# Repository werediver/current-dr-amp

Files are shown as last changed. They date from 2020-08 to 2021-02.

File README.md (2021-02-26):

# CURRENT DR.

This is a "current drive" or VCCS class A headphone amplifier. Some advocacy of current drive (as well as a whole book on the topic) can be found at [current-drive.info](https://www.current-drive.info/6).

The first prototype is briefly described on [Prototype](texts/prototype.md) page.

## Schematic

The current version of the schematic is showed below.

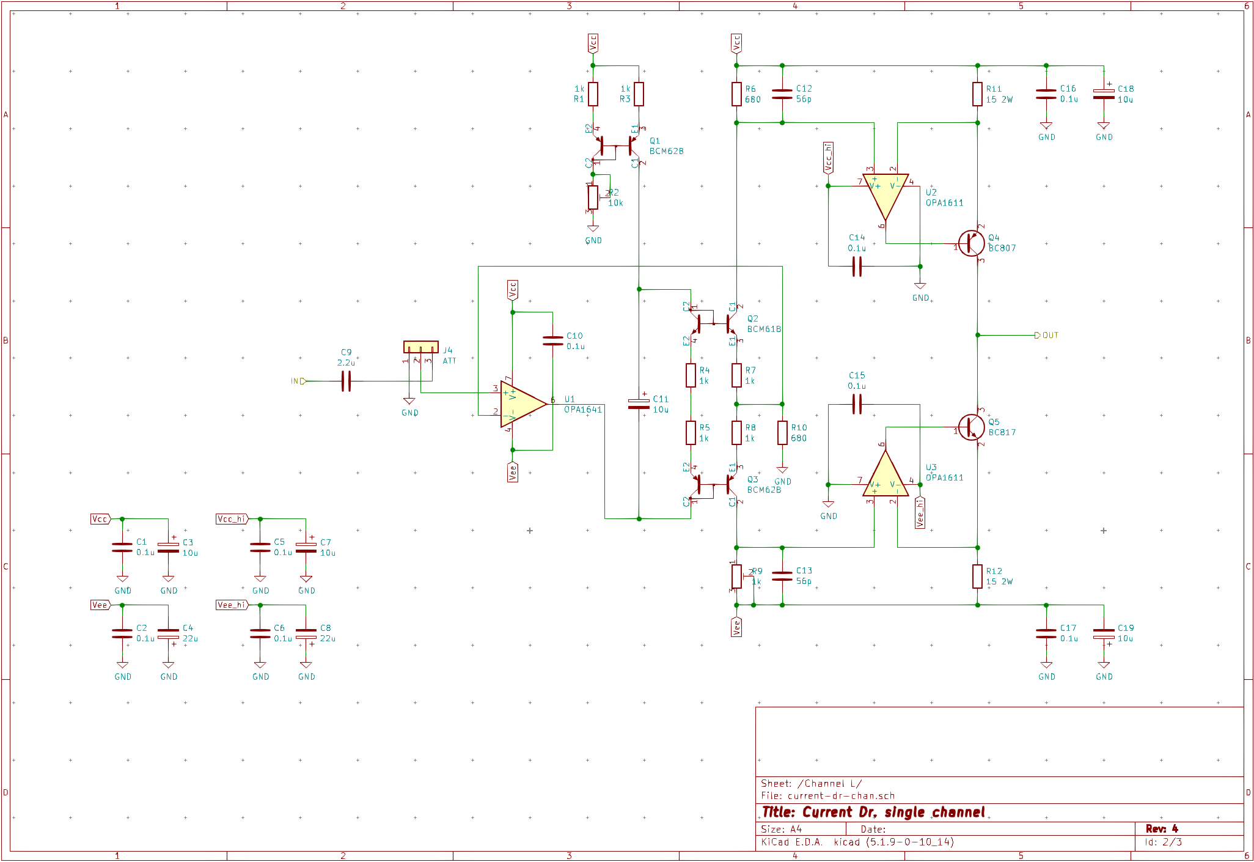
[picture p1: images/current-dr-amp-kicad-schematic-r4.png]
Current Dr. schematic


Two such channels with a dedicated [linear PSU](texts/psu.md) are going to be fit into an extruded aluminum enclosure with internal dimensions of 96x155x50 mm.

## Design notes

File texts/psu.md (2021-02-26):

# Power supply unit

A double bipolar linear PSU with discrete low-dropout voltage regulators is designed for Current Dr. amplifier.

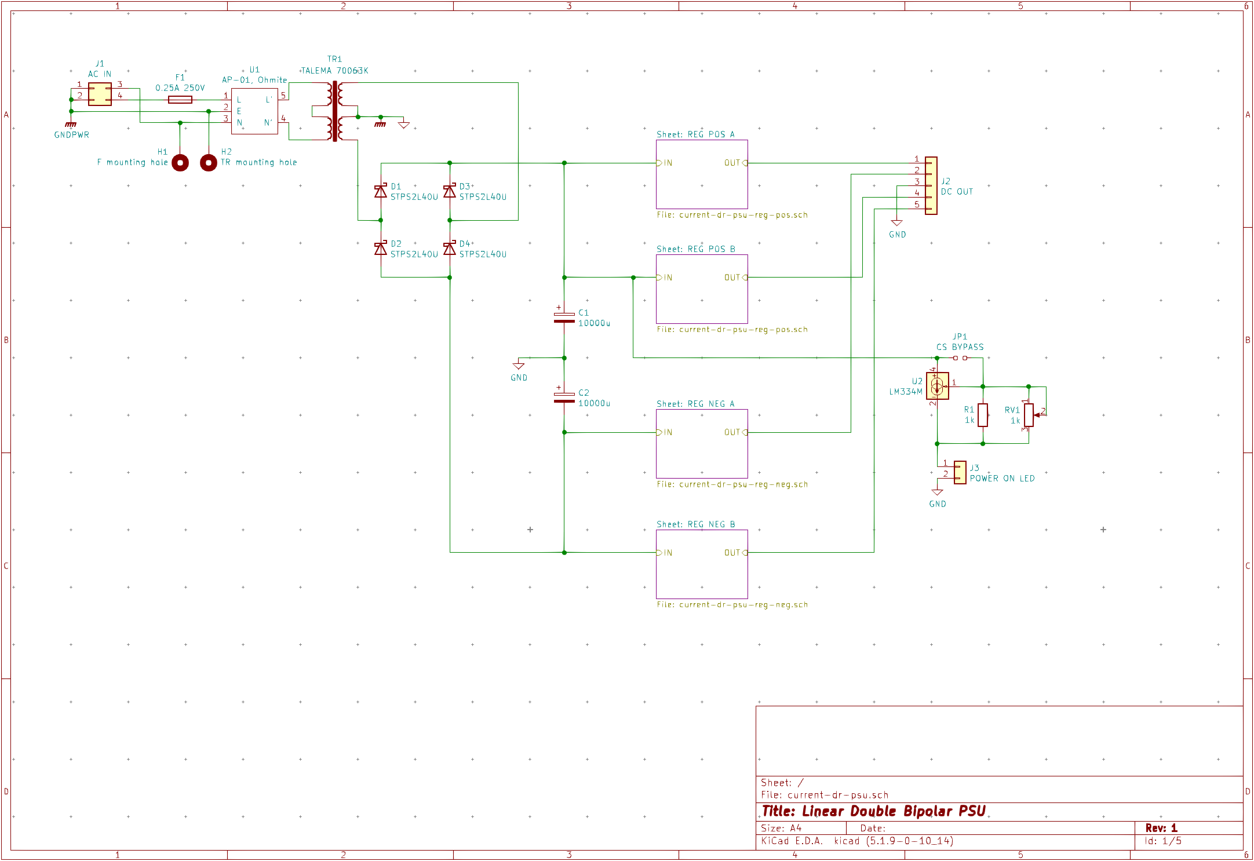
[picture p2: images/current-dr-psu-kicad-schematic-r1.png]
Top-level PSU schematic


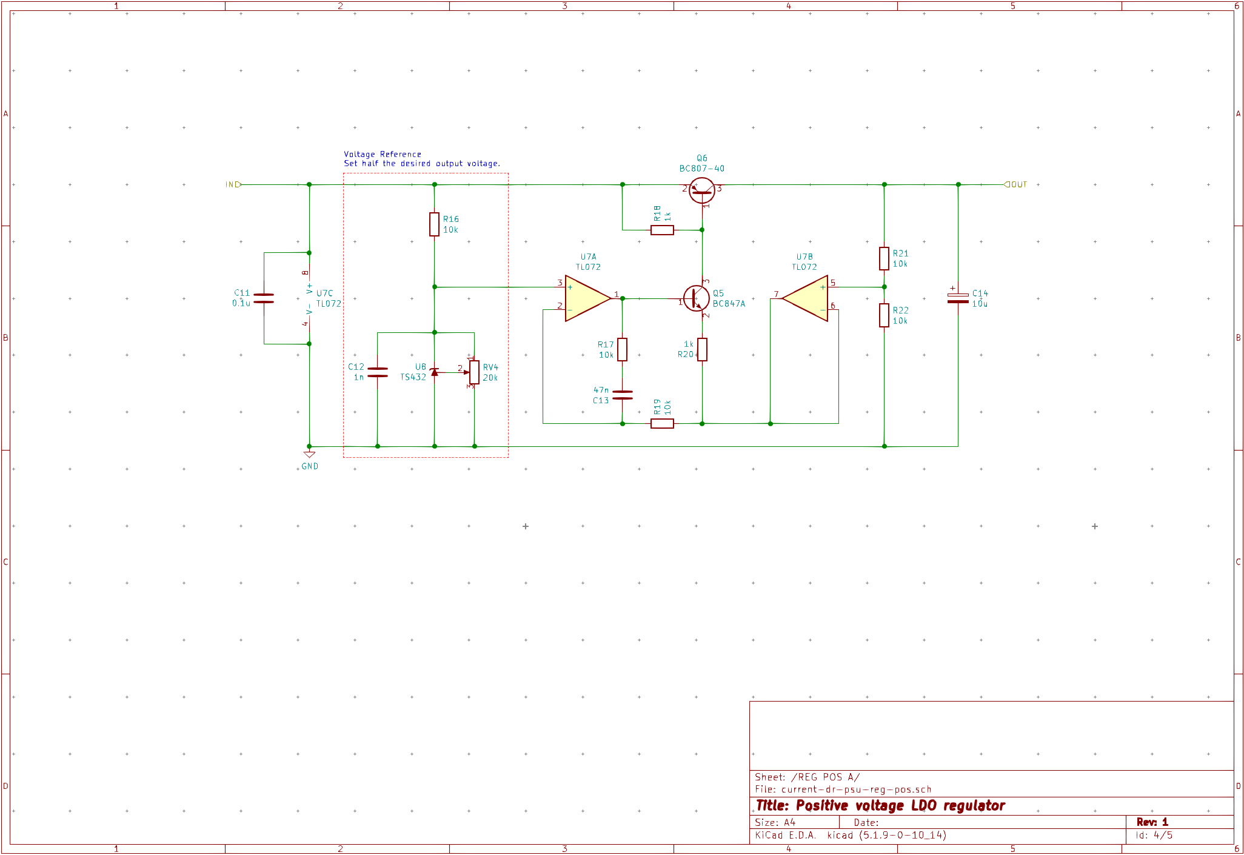
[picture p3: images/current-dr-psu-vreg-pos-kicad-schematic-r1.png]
Discrete positive low-dropout voltage regulator


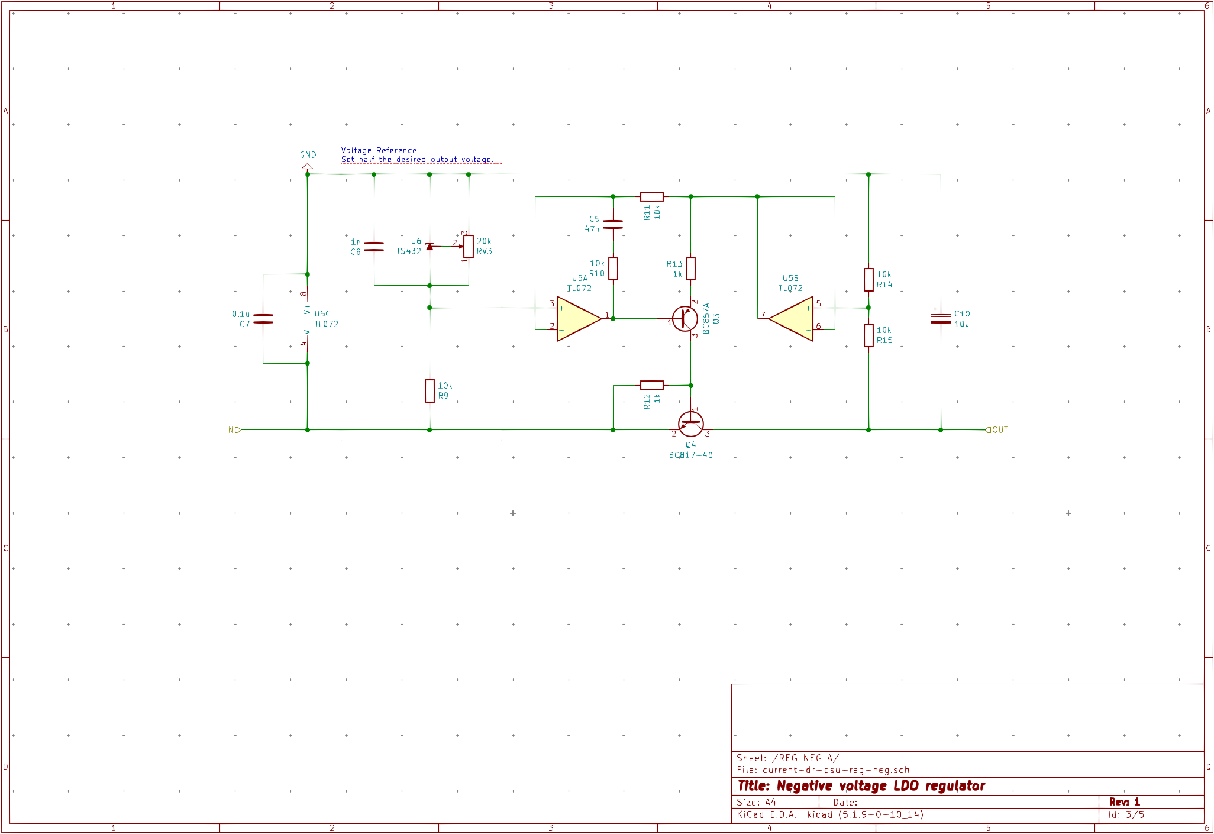
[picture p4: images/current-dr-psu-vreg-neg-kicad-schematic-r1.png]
Discrete negative low-dropout voltage regulator


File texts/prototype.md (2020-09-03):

# Prototype

A single channel of the Current Dr. amplifier has been prototyped according to the following schematic.

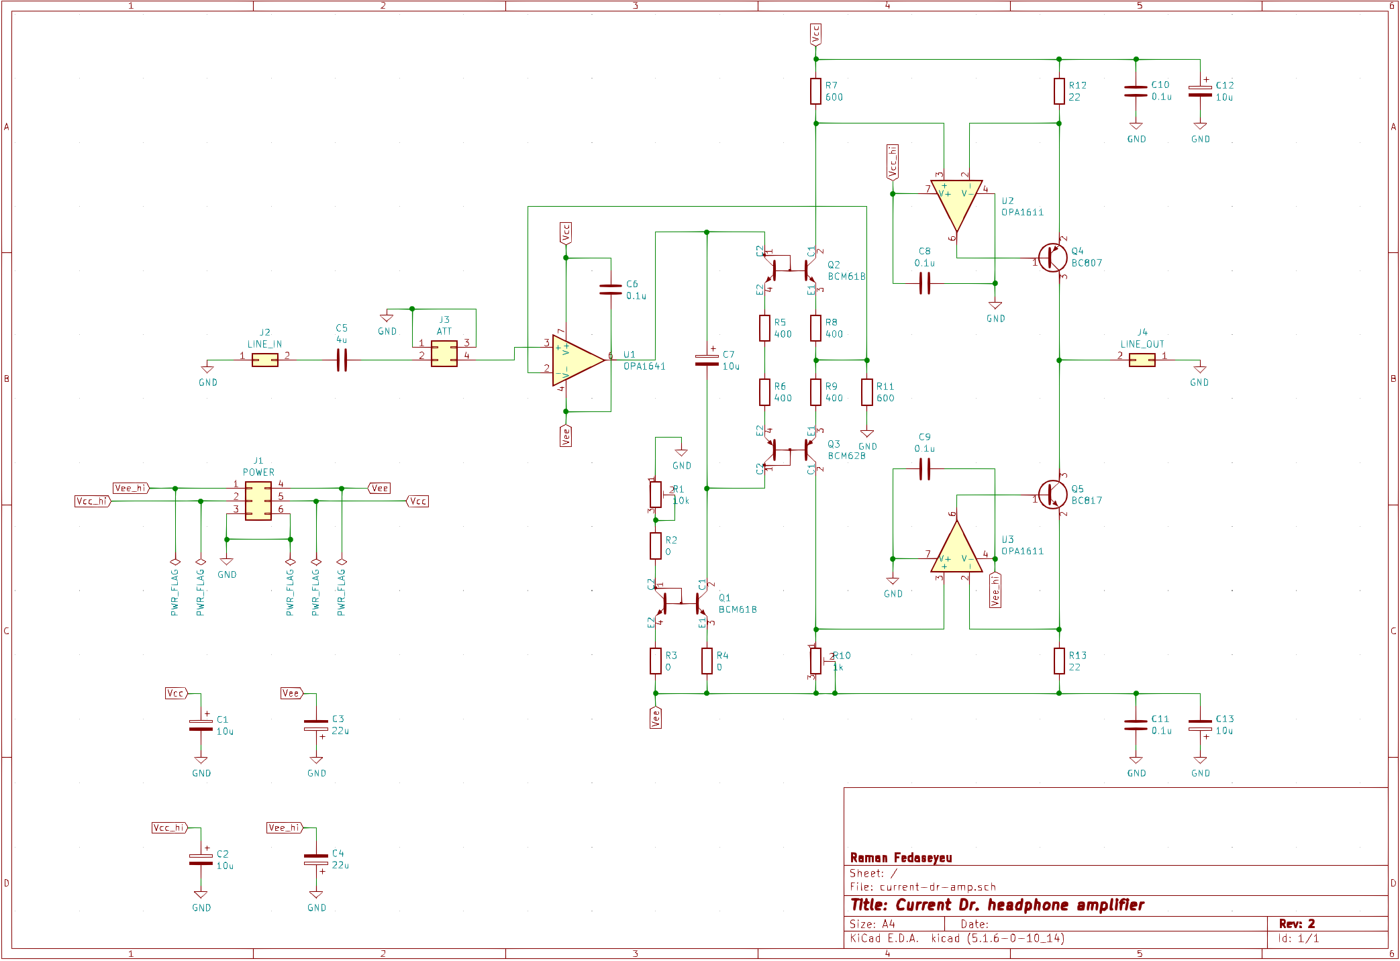
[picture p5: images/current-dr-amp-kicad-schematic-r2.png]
KiCad schematic


There are a few placeholder components present (R2–R4) and some were added after debugging the prototype (C1–C4).

The initial set-up consists of two operations:

- setting the quiescent current through the reference current sink Q2–Q3 to about 2.5 mA by adjusting R1 and measuring the voltage drop across R5–R6
- setting the output DC offset to a fraction of a mV by adjusting R10 and measuring voltage at the output with a load connected (a resistor of a few hundreds ohm is a suitable load)

The assembled prototype looks like this.

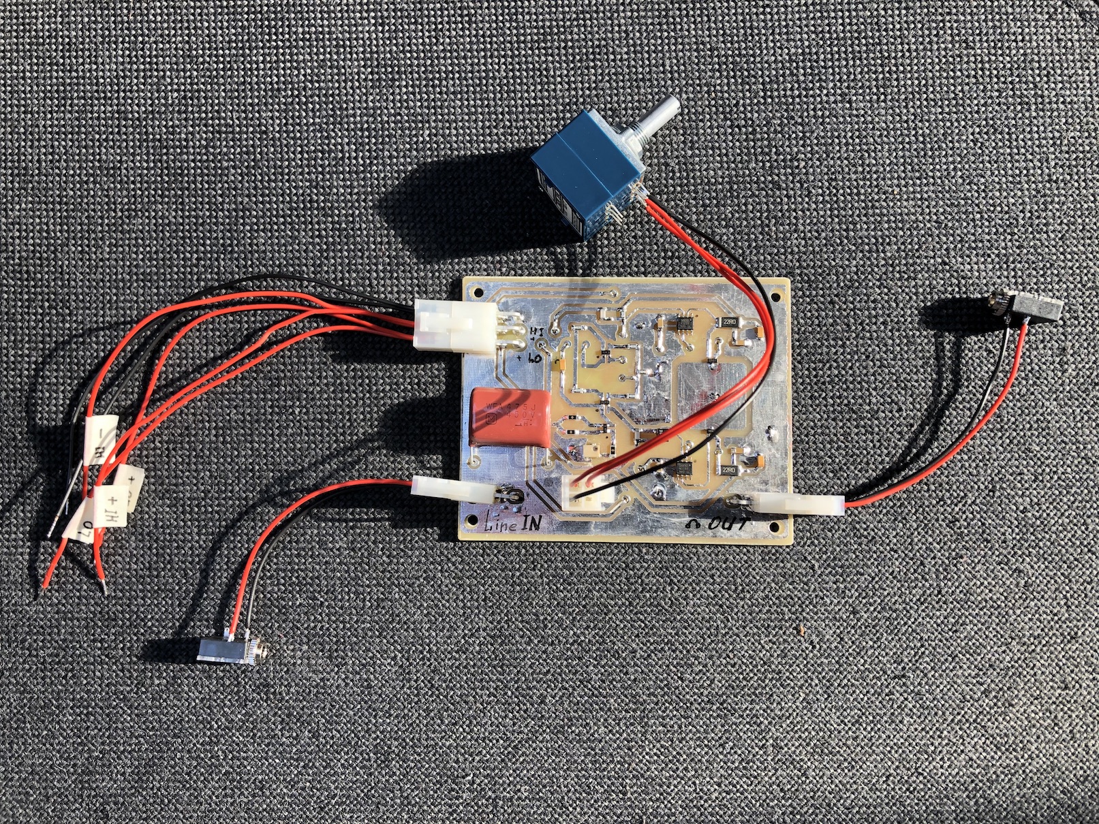
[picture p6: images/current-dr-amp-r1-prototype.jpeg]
Prototype


I haven't been able to measure the frequency response, THD, or the output impedance of the prototype yet. Listening to a single channel output suggests it has some potential, hence a proper characterization and development of a standalone stereo amplifier is to be done.

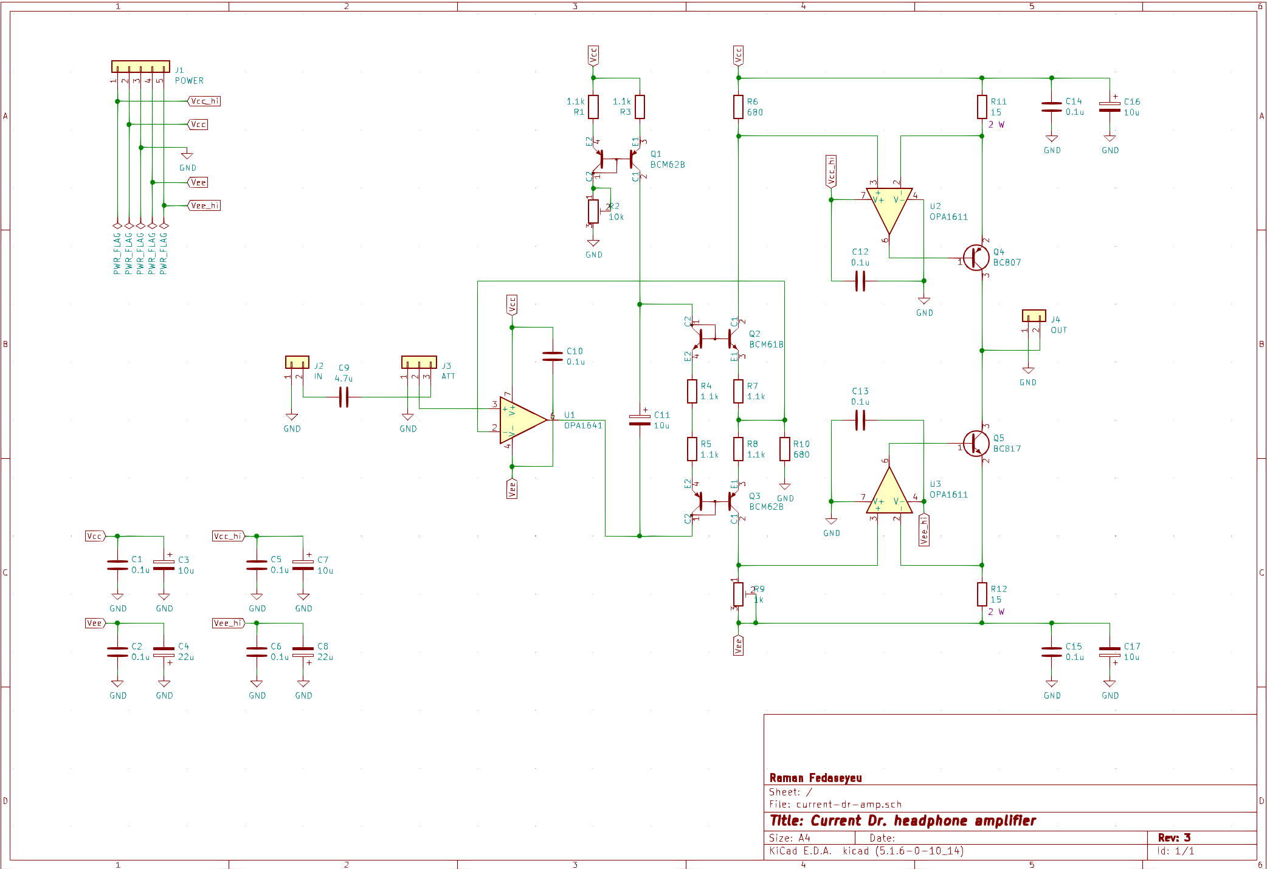
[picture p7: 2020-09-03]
images/current-dr-amp-kicad-schematic-r3.png

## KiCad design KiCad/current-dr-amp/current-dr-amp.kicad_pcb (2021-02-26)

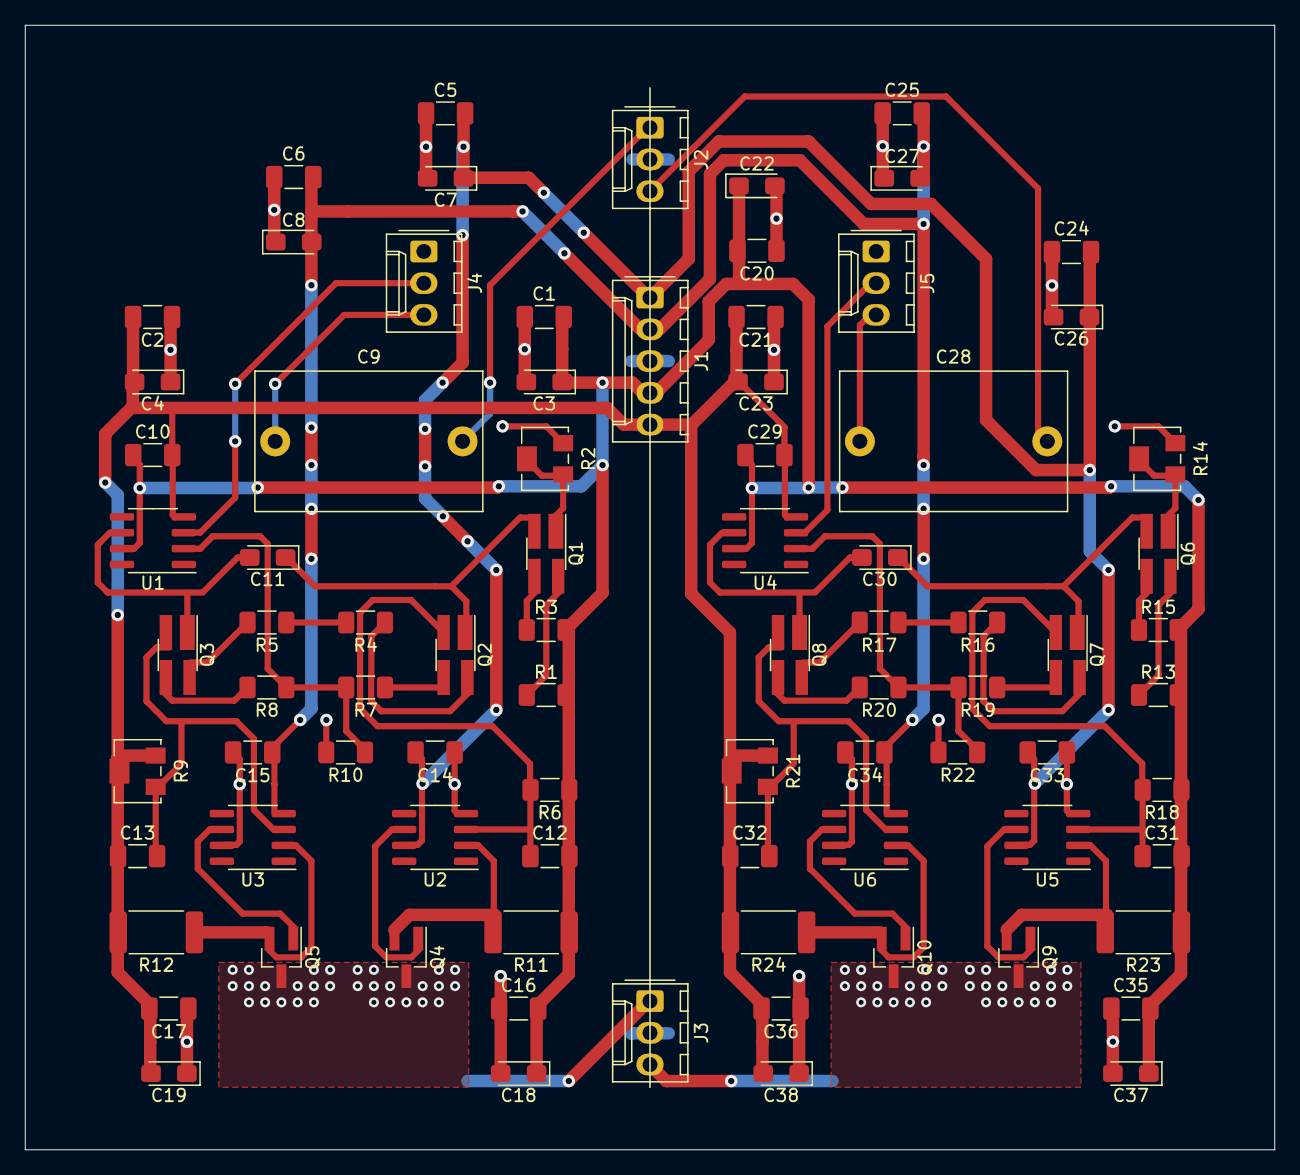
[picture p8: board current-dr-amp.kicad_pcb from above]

Board: 2 copper layers, 100.0 x 90.0 mm, 83 parts (0 on the bottom side), 47 nets.

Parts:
C1, C2, C5, C6, C10, C14, C15, C16, C17, C20, C21, C24, C25, C29, C33, C34, C35, C36: 0.1u; C_1206_3216Metric_Pad1.33x1.80mm_HandSolder
C3, C7, C11, C18, C19, C22, C26, C30, C37, C38: 10u; CP_EIA-3216-10_Kemet-I_Pad1.58x1.35mm_HandSolder
C4, C8, C23, C27: 22u; CP_EIA-3216-10_Kemet-I_Pad1.58x1.35mm_HandSolder
C9, C28: 2.2u; C_Rect_L18.0mm_W11.0mm_P15.00mm_FKS3_FKP3
C12, C13, C31, C32: 56p; C_1206_3216Metric_Pad1.33x1.80mm_HandSolder
J1: POWER; Molex_KK-254_AE-6410-05A_1x05_P2.54mm_Vertical
J2: IN; Molex_KK-254_AE-6410-03A_1x03_P2.54mm_Vertical
J3: OUT; Molex_KK-254_AE-6410-03A_1x03_P2.54mm_Vertical
J4, J5: ATT; Molex_KK-254_AE-6410-03A_1x03_P2.54mm_Vertical
Q1, Q3, Q6, Q8: BCM62B; SOT-143_Handsoldering
Q2, Q7: BCM61B; SOT-143_Handsoldering
Q4, Q9: BC807; SOT-23_Handsoldering
Q5, Q10: BC817; SOT-23_Handsoldering
R1, R3, R4, R5, R7, R8, R13, R15, R16, R17, R19, R20: 1k; R_1206_3216Metric_Pad1.30x1.75mm_HandSolder
R2, R14: 10k; Potentiometer_Bourns_3224W_Vertical
R6, R10, R18, R22: 680; R_1206_3216Metric_Pad1.30x1.75mm_HandSolder
R9, R21: 1k; Potentiometer_Bourns_3224W_Vertical
R11, R12, R23, R24: 15 2W; R_2512_6332Metric_Pad1.40x3.35mm_HandSolder
U1, U4: OPA1641; SOIC-8_3.9x4.9mm_P1.27mm
U2, U3, U5, U6: OPA1611; SOIC-8_3.9x4.9mm_P1.27mm

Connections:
/Channel L/IN: C9.2, J2.1
/Channel L/OUT: J3.1, Q4.3, Q5.3
/Channel R/IN: C28.2, J2.3
/Channel R/OUT: J3.3, Q9.3, Q10.3
GND: C1.1, C2.1, C3.2, C4.1, C5.1, C6.1, C7.2, C8.1, C14.1, C15.2, C16.1, C17.1, C18.2, C19.1, C20.1, C21.1, C22.2, C23.1, C24.1, C25.1, C26.2, C27.1, C33.1, C34.2, C35.1, C36.1, C37.2, C38.1, J1.3, J2.2, J3.2, J4.1, J5.1, R2.3, R10.2, R14.3, R22.2, U2.4, U3.7, U5.4, U6.7
unnamed: C9.1, J4.3
unnamed: C11.1, Q1.2, Q2.1
unnamed: C11.2, Q3.1, U1.6
unnamed: C12.1, Q2.2, R6.2, U2.3
unnamed: C13.2, Q3.2, R9.1, U3.3
unnamed: C28.1, J5.3
unnamed: C30.1, Q6.2, Q7.1
unnamed: C30.2, Q8.1, U4.6
unnamed: C31.1, Q7.2, R18.2, U5.3
unnamed: C32.2, Q8.2, R21.1, U6.3
unnamed: J4.2, U1.3
unnamed: J5.2, U4.3
unnamed: Q1.1, R2.1, R2.2
unnamed: Q1.3, R3.1
unnamed: Q1.4, R1.1
unnamed: Q2.3, R7.1
unnamed: Q2.4, R4.1
unnamed: Q3.3, R8.2
unnamed: Q3.4, R5.2
unnamed: Q4.1, U2.6
unnamed: Q4.2, R11.2, U2.2
unnamed: Q5.1, U3.6
unnamed: Q5.2, R12.1, U3.2
unnamed: Q6.1, R14.1, R14.2
unnamed: Q6.3, R15.1
unnamed: Q6.4, R13.1
unnamed: Q7.3, R19.1
unnamed: Q7.4, R16.1
unnamed: Q8.3, R20.2
unnamed: Q8.4, R17.2
unnamed: Q9.1, U5.6
unnamed: Q9.2, R23.2, U5.2
unnamed: Q10.1, U6.6
unnamed: Q10.2, R24.1, U6.2
unnamed: R4.2, R5.1
unnamed: R7.2, R8.1, R10.1, U1.2
unnamed: R16.2, R17.1
unnamed: R19.2, R20.1, R22.1, U4.2
Vcc: C1.2, C3.1, C10.1, C12.2, C16.2, C18.1, C20.2, C22.1, C29.1, C31.2, C35.2, C37.1, J1.4, R1.2, R3.2, R6.1, R11.1, R13.2, R15.2, R18.1, R23.1, U1.7, U4.7
Vcc_hi: C5.2, C7.1, C14.2, C24.2, C26.1, C33.2, J1.1, U2.7, U5.7
Vee: C2.2, C4.2, C10.2, C13.1, C17.2, C19.2, C21.2, C23.2, C29.2, C32.1, C36.2, C38.2, J1.5, R9.2, R9.3, R12.2, R21.2, R21.3, R24.2, U1.4, U4.4
Vee_hi: C6.2, C8.2, C15.1, C25.2, C27.2, C34.1, J1.2, U3.4, U6.4

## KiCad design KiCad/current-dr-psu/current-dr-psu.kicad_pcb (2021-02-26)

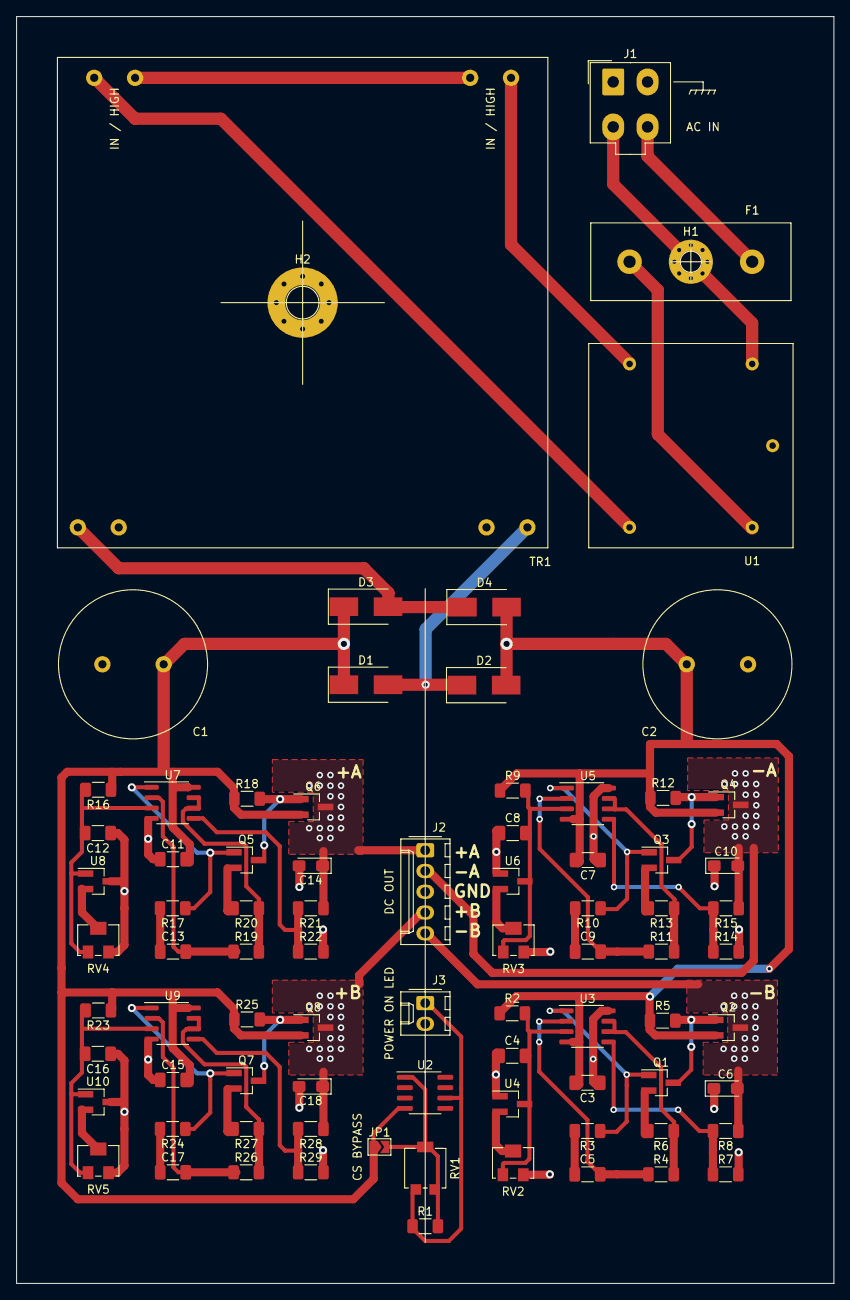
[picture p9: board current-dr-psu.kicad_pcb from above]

Board: 2 copper layers, 100.0 x 155.0 mm, 82 parts (0 on the bottom side), 53 nets.

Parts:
C1, C2: 10000u; C_Radial_D18.0mm_H35.5mm_P7.50mm
C3, C7, C11, C15: 0.1u; C_1206_3216Metric_Pad1.33x1.80mm_HandSolder
C4, C8, C12, C16: 1n; C_1206_3216Metric_Pad1.33x1.80mm_HandSolder
C5, C9, C13, C17: 47n; C_1206_3216Metric_Pad1.33x1.80mm_HandSolder
C6, C10, C14, C18: 10u; CP_EIA-3216-10_Kemet-I_Pad1.58x1.35mm_HandSolder
D1, D2, D3, D4: STPS2L40U; D_SMB_Handsoldering
F1: 0.25A 250V; FUSE_5x20_Stelvio-Kontek_PTF75
H1: F mounting hole; MountingHole_2.7mm_Pad_Via
H2: TR mounting hole; MountingHole_4.3mm_M4_Pad_Via
J1: AC IN; Molex_Mini-Fit_Jr_5566-04A_2x02_P4.20mm_Vertical
J2: DC OUT; Molex_KK-254_AE-6410-05A_1x05_P2.54mm_Vertical
J3: POWER ON LED; Molex_KK-254_AE-6410-02A_1x02_P2.54mm_Vertical
JP1: CS BYPASS; SolderJumper-2_P1.3mm_Open_TrianglePad1.0x1.5mm
Q1, Q3: BC857A; SOT-23_Handsoldering
Q2, Q4: BC817-40; SOT-23_Handsoldering
Q5, Q7: BC847A; SOT-23_Handsoldering
Q6, Q8: BC807-40; SOT-23_Handsoldering
R1, R5, R6, R12, R13, R18, R20, R25, R27: 1k; R_1206_3216Metric_Pad1.30x1.75mm_HandSolder
R2, R3, R4, R7, R8, R9, R10, R11, R14, R15, R16, R17, R19, R21, R22, R23, R24, R26, R28, R29: 10k; R_1206_3216Metric_Pad1.30x1.75mm_HandSolder
RV1: 1k; Potentiometer_Bourns_3214G_Horizontal
RV2, RV3, RV4, RV5: 20k; Potentiometer_Bourns_3224W_Vertical
TR1: TALEMA 70063K; TF_60x60
U1: AP-01, Ohmite; EMI_FILTER_25x25
U2: LM334M; SOIC-8_3.9x4.9mm_P1.27mm
U3, U5, U7, U9: TL072; SO-8_3.9x4.9mm_P1.27mm
U4, U6, U8, U10: TS432; SOT-23_Handsoldering

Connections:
/REG NEG A/IN: C2.2, C3.2, C7.2, D2.2, D4.2, Q2.2, Q4.2, R2.1, R5.1, R9.1, R12.1, U3.4, U5.4
/REG NEG A/OUT: C10.2, J2.2, Q4.3, R15.1
/REG NEG B/OUT: C6.2, J2.5, Q2.3, R8.1
/REG POS A/IN: C1.1, C11.2, C15.2, D1.1, D3.1, JP1.1, Q6.2, Q8.2, R16.1, R18.1, R23.1, R25.1, U2.4, U7.8, U9.8
/REG POS A/OUT: C14.1, J2.1, Q6.3, R21.1
/REG POS B/OUT: C18.1, J2.4, Q8.3, R28.1
GND: C1.2, C2.1, C3.1, C4.1, C6.1, C7.1, C8.1, C10.1, C11.1, C12.1, C14.2, C15.1, C16.1, C18.2, H2.1, J1.1, J1.2, J2.3, J3.2, R7.2, R14.2, R22.2, R29.2, RV2.3, RV3.3, RV4.3, RV5.3, TR1.6, TR1.7, U1.2, U3.8, U4.1, U5.8, U6.1, U7.4, U8.3, U9.4, U10.3
unnamed: C4.2, R2.2, RV2.1, U3.3, U4.3
unnamed: C5.1, R3.2
unnamed: C5.2, R4.1, U3.2
unnamed: C8.2, R9.2, RV3.1, U5.3, U6.3
unnamed: C9.1, R10.2
unnamed: C9.2, R11.1, U5.2
unnamed: C12.2, R16.2, RV4.1, U7.3, U8.1
unnamed: C13.1, R17.2
unnamed: C13.2, R19.1, U7.2
unnamed: C16.2, R23.2, RV5.1, U9.3, U10.1
unnamed: C17.1, R24.2
unnamed: C17.2, R26.1, U9.2
unnamed: D1.2, D2.1, TR1.8
unnamed: D3.2, D4.1, TR1.5
unnamed: F1.1, J1.4
unnamed: F1.2, U1.1
unnamed: H1.1, J1.3, U1.3
unnamed: J3.1, R1.1, RV1.3, U2.6
unnamed: JP1.2, R1.2, RV1.1, RV1.2, U2.1
unnamed: Q1.1, R3.1, U3.1
unnamed: Q1.2, R6.2
unnamed: Q1.3, Q2.1, R5.2
unnamed: Q3.1, R10.1, U5.1
unnamed: Q3.2, R13.2
unnamed: Q3.3, Q4.1, R12.2
unnamed: Q5.1, R17.1, U7.1
unnamed: Q5.2, R20.2
unnamed: Q5.3, Q6.1, R18.2
unnamed: Q7.1, R24.1, U9.1
unnamed: Q7.2, R27.2
unnamed: Q7.3, Q8.1, R25.2
unnamed: R4.2, R6.1, U3.6, U3.7
unnamed: R7.1, R8.2, U3.5
unnamed: R11.2, R13.1, U5.6, U5.7
unnamed: R14.1, R15.2, U5.5
unnamed: R19.2, R20.1, U7.6, U7.7
unnamed: R21.2, R22.1, U7.5
unnamed: R26.2, R27.1, U9.6, U9.7
unnamed: R28.2, R29.1, U9.5
unnamed: RV2.2, U4.2
unnamed: RV3.2, U6.2
unnamed: RV4.2, U8.2
unnamed: RV5.2, U10.2
unnamed: TR1.1, U1.4
unnamed: TR1.2, TR1.3
unnamed: TR1.4, U1.5

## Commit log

2020-08-26 Add ".gitignore" to ignore some KiCad files
2020-08-26 Add a KiCad project (schematic & PCB) of a prototype version
    [current-dr-amp.kicad_pcb, current-dr-amp.sch]
2020-08-26 Add "Prototype" section to README
2020-08-26 Add some metadata to the schematic, update the schematic image
    [current-dr-amp.sch]
2020-08-29 Force Git to generate text diffs for LTspice schematics ("*.asc")
2020-08-29 Update the LTspice model
    - use ±14/16 V instead of ±9/15V
    - increase max output current to ~236 mA (~1 W with 38 Ohm load)
    - move the quiescent current source to Vcc
2020-08-29 Update the KiCad schematic according to the LTspice model
    [current-dr-amp.sch]
2020-09-03 Update README
    and extract the prototype description into a separate file
2020-09-03 Fix an error in the input part of the KiCad schematic
    [current-dr-amp.sch]
2021-02-26 Update KiCad schematics and PCBs to the lates version
    [current-dr-amp.kicad_pcb, current-dr-amp.sch, current-dr-chan.sch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]
2021-02-26 Update README to present the latest schematic versions
    and to refer to the PSU description
